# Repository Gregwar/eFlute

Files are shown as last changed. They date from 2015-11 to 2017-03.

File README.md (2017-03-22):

# eFlute

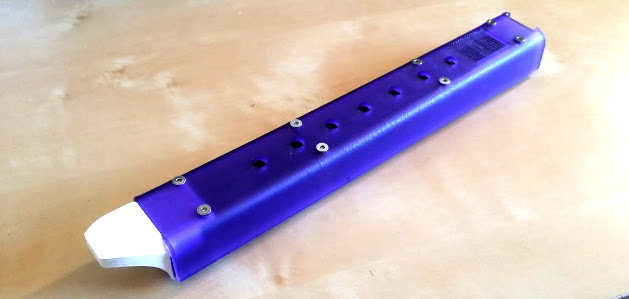
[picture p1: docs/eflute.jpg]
eFlute


**WARNING: This is still a work in progress, which is really poorly documented and with uncertain release date and evolution**

## Video

[Here is a video of an old version of the flute](https://www.youtube.com/watch?v=Vu05FvypGyI)

## License

This project is under CC-BY-NC license. If you're not sure about what you can
do, you should ask the author Grégoire Passault (g.passault@gmail.com).

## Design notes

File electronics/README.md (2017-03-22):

# Electronics

Here are (eagle) files to build the PCB

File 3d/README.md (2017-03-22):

# 3D Design

Here are the 3D files, you'll need Autodesk Inventor to open the ipt/iam
design files

You'll also find STL ready to print for the mouthpiece

Also, there is DXF files to build the acrylic chassis using 3D cutting,
note that you'll also need to bend those pieces.

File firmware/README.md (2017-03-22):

# Firmware

## Bootloader

First, you'll need to flash an USB bootloader on the STM32F103,
you can use either Maple bootloader or ROBOTIS bootloader. This
will be documented later.

## Building and flashing

To build and flash the firmware:

	./prepare.sh
	make
	make install

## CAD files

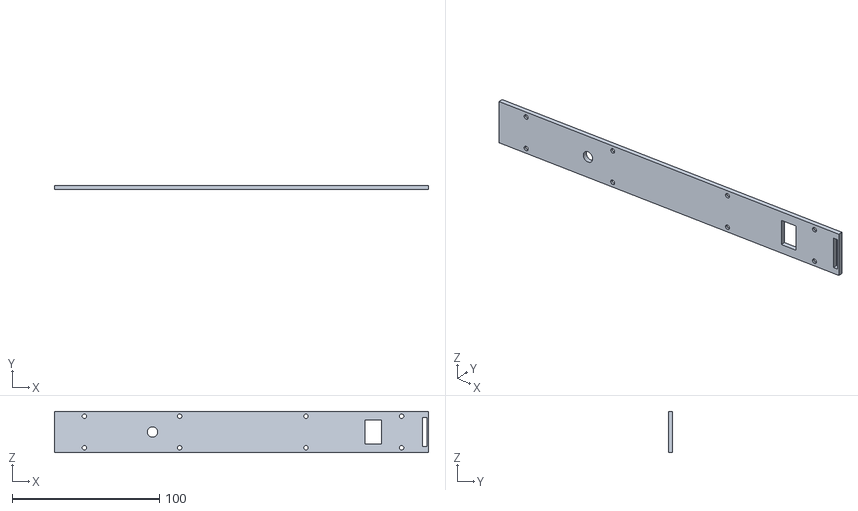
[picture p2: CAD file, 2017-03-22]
3d/bottom.stl
254.0 x 3.00 x 28.0

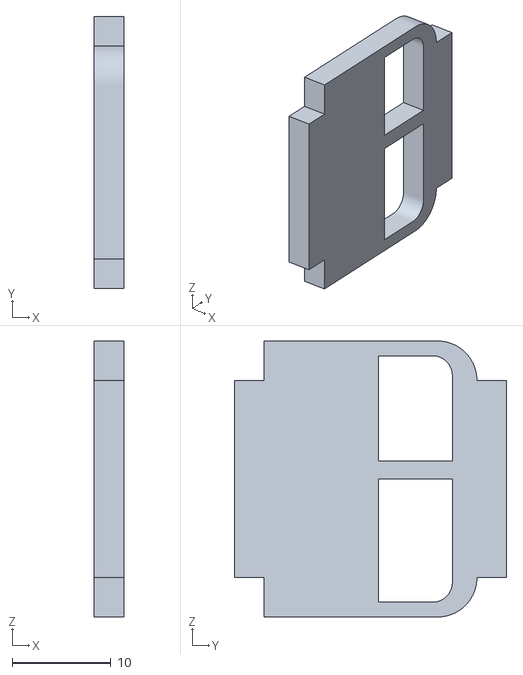
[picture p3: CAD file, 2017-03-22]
3d/connectors.stl
3.00 x 27.6 x 28.0

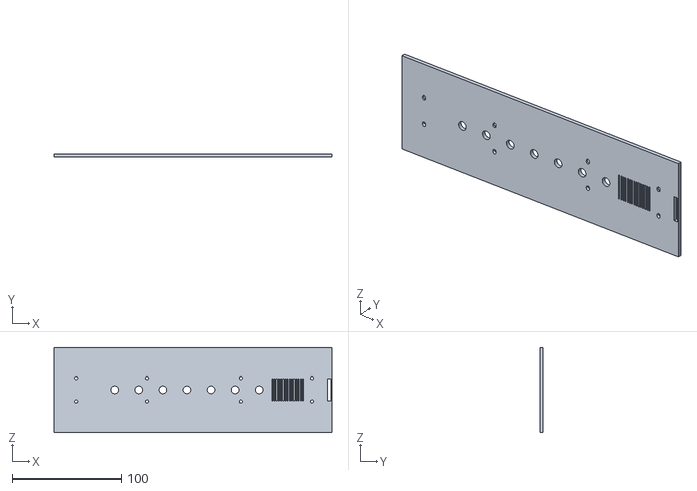
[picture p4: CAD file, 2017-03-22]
3d/top.stl
254.0 x 3.00 x 77.9

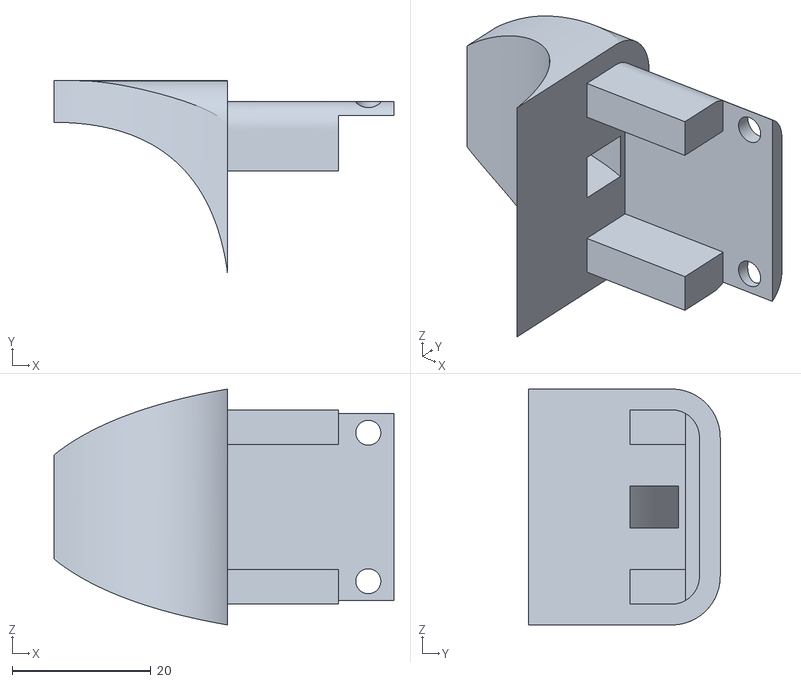
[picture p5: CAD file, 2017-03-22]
3d/mouthpiece.stl
49.0 x 27.6 x 34.0

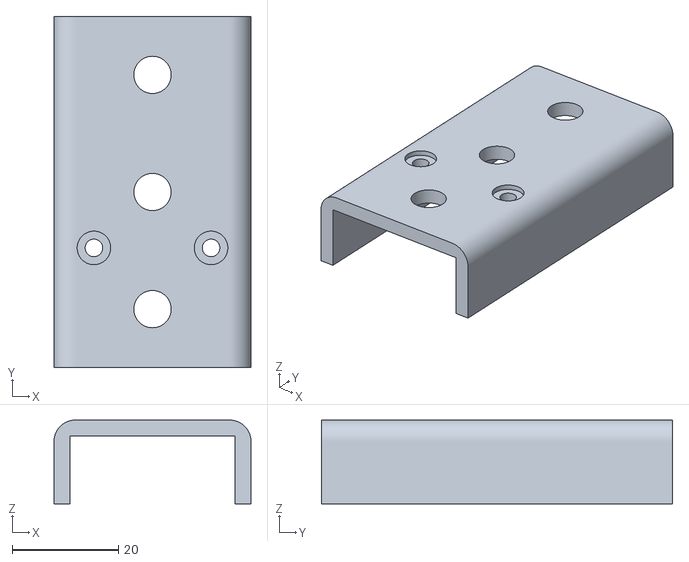
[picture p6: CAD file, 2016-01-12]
3d/part2_top.stl
37.0 x 66.0 x 15.8

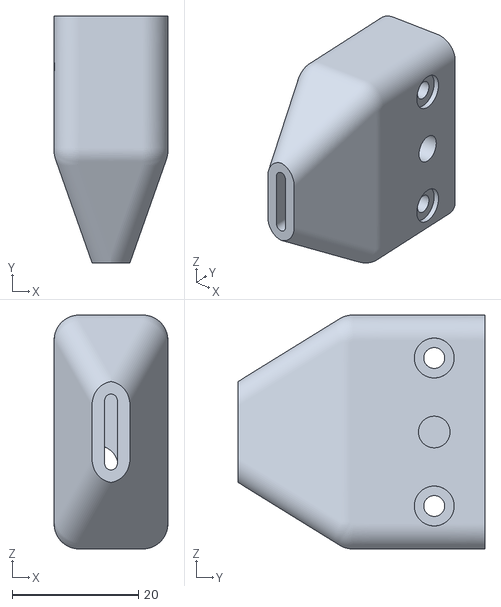
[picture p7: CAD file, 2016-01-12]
3d/mouth.stl
18.0 x 39.0 x 37.0

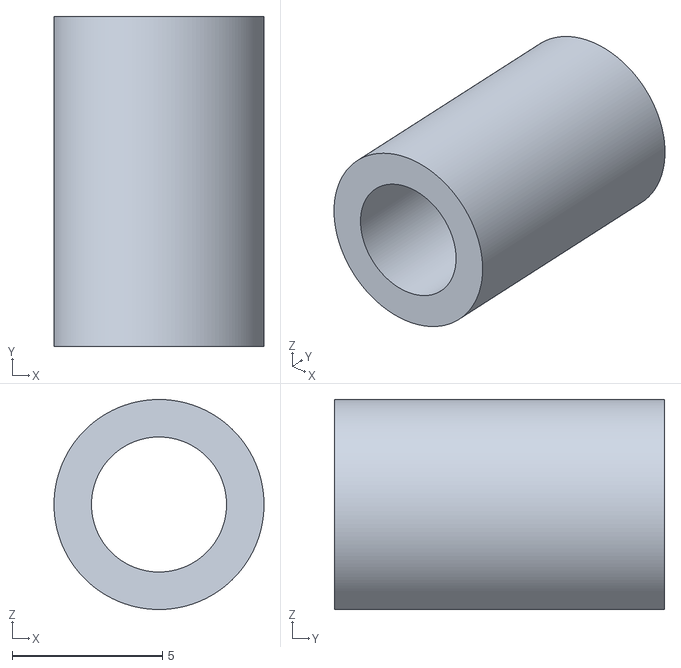
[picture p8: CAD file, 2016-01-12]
3d/entretoise_11.stl
7.00 x 11.0 x 7.00

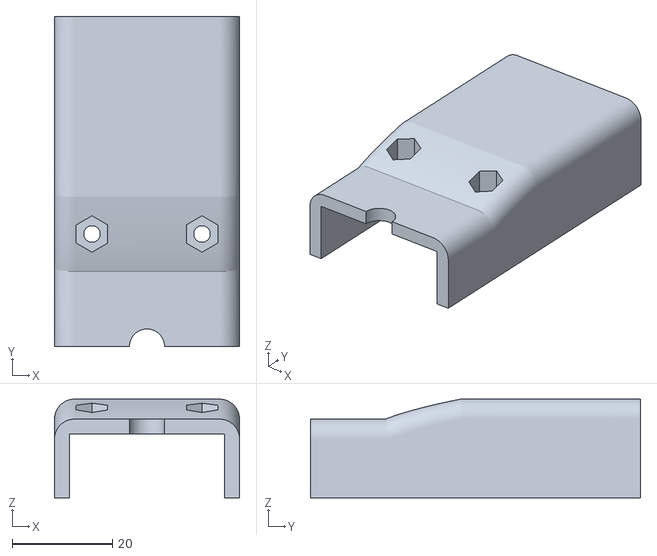
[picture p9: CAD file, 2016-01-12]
3d/part2_bottom.stl
37.0 x 66.0 x 19.8

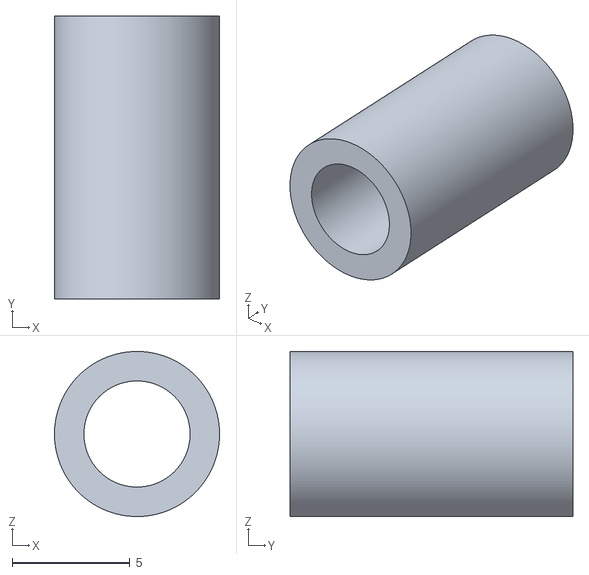
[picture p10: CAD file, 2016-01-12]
3d/entretoise_12.stl
7.00 x 12.0 x 7.00

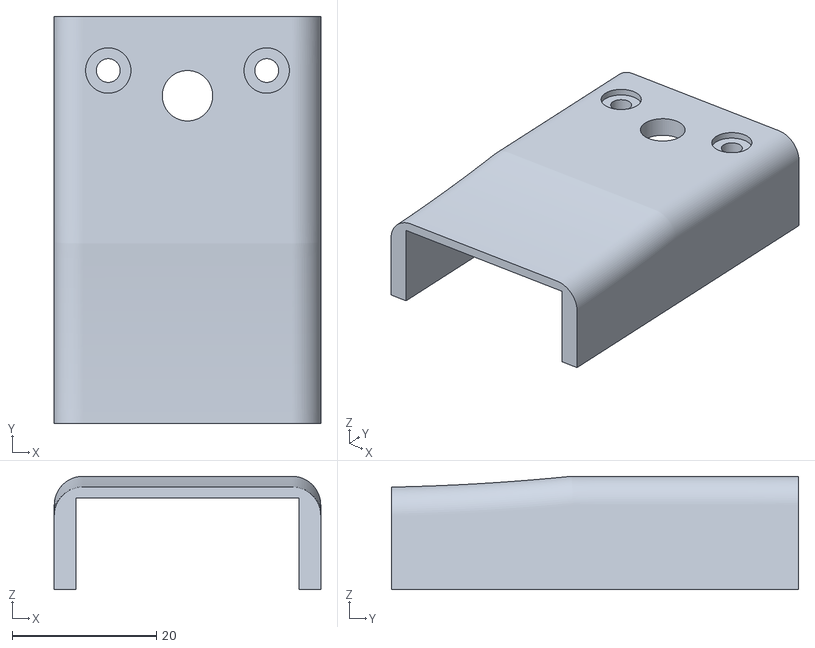
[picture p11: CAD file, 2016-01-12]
3d/part1_top.stl
37.0 x 56.5 x 15.8

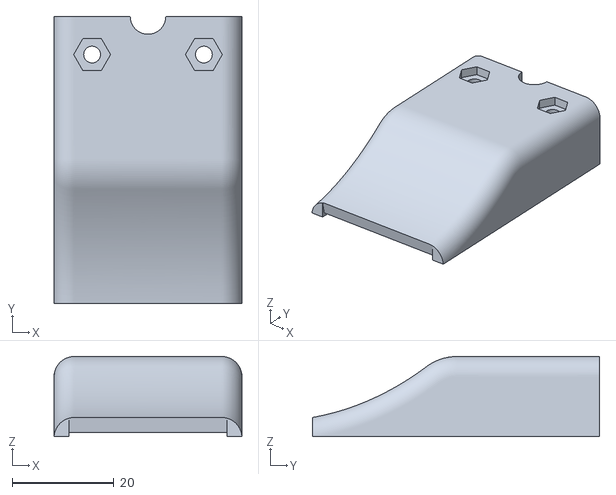
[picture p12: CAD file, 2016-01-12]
3d/part1_bottom.stl
37.0 x 56.5 x 15.8

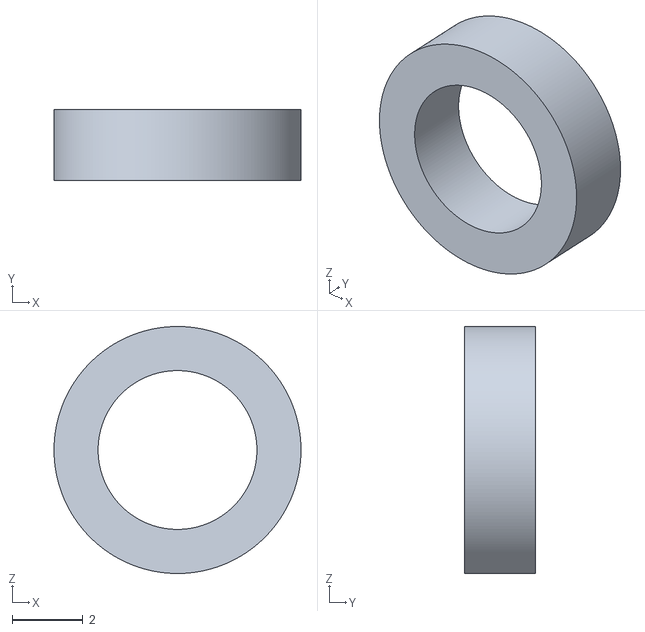
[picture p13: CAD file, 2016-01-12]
3d/entretoise_2.stl
7.00 x 2.00 x 7.00

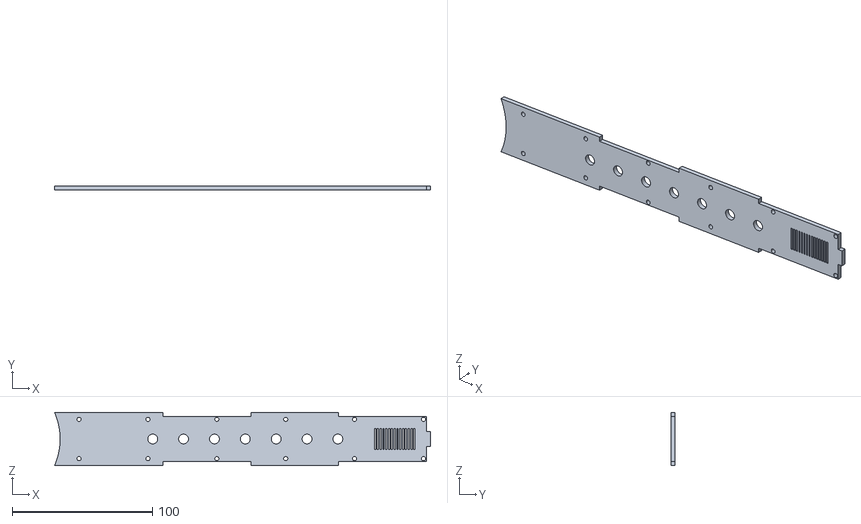
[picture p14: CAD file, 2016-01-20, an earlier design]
3d/v1.1/top.stl
268.0 x 3.00 x 38.0

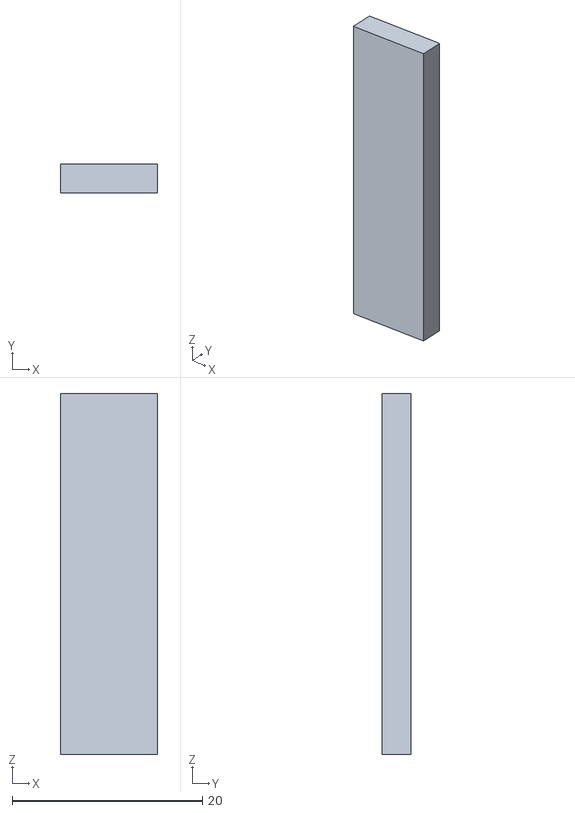
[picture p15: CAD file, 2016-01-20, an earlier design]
3d/v1/renfort.stl
10.2 x 3.00 x 38.0

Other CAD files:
3d/part3_top.stl
3d/v1.1/side.stl
3d/v1/bottom2.stl
3d/v1.1/bottom.stl
3d/bottom.dxf
3d/bottom.ipt
3d/connectors.dxf
3d/connectors.ipt
3d/countersunk.ipt
3d/countersunk_MIR.ipt
3d/electronics.ipt
3d/entretoise_11.ipt
3d/entretoise_12.ipt
3d/entretoise_16.ipt
3d/entretoise_2.ipt
3d/flute.iam
3d/mouth.ipt
3d/mouthpiece.ipt
3d/part1_bottom.ipt
3d/part1_top.ipt
3d/part2_bottom.ipt
3d/part2_top.ipt
3d/part3_top.ipt
3d/spacer_6.ipt
3d/spacer_8.ipt
3d/speaker.ipt
3d/top.dxf
3d/top.ipt
3d/v1.1/bec.ipt
3d/v1.1/bec.stl
3d/v1.1/bottom.ipt
3d/v1.1/bottom2.ipt
3d/v1.1/bottom2.stl
3d/v1.1/bottom_renfort.ipt
3d/v1.1/bottom_renfort.stl
3d/v1.1/button.ipt
3d/v1.1/button.stl
3d/v1.1/cache.ipt
3d/v1.1/coffre.ipt
3d/v1.1/connectors.ipt
3d/v1.1/connectors.stl
3d/v1.1/electronics.ipt
3d/v1.1/flute.iam
3d/v1.1/plate_001.stl
3d/v1.1/renfort.ipt
3d/v1.1/side.ipt
3d/v1.1/side_sym.ipt
3d/v1.1/top.ipt
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

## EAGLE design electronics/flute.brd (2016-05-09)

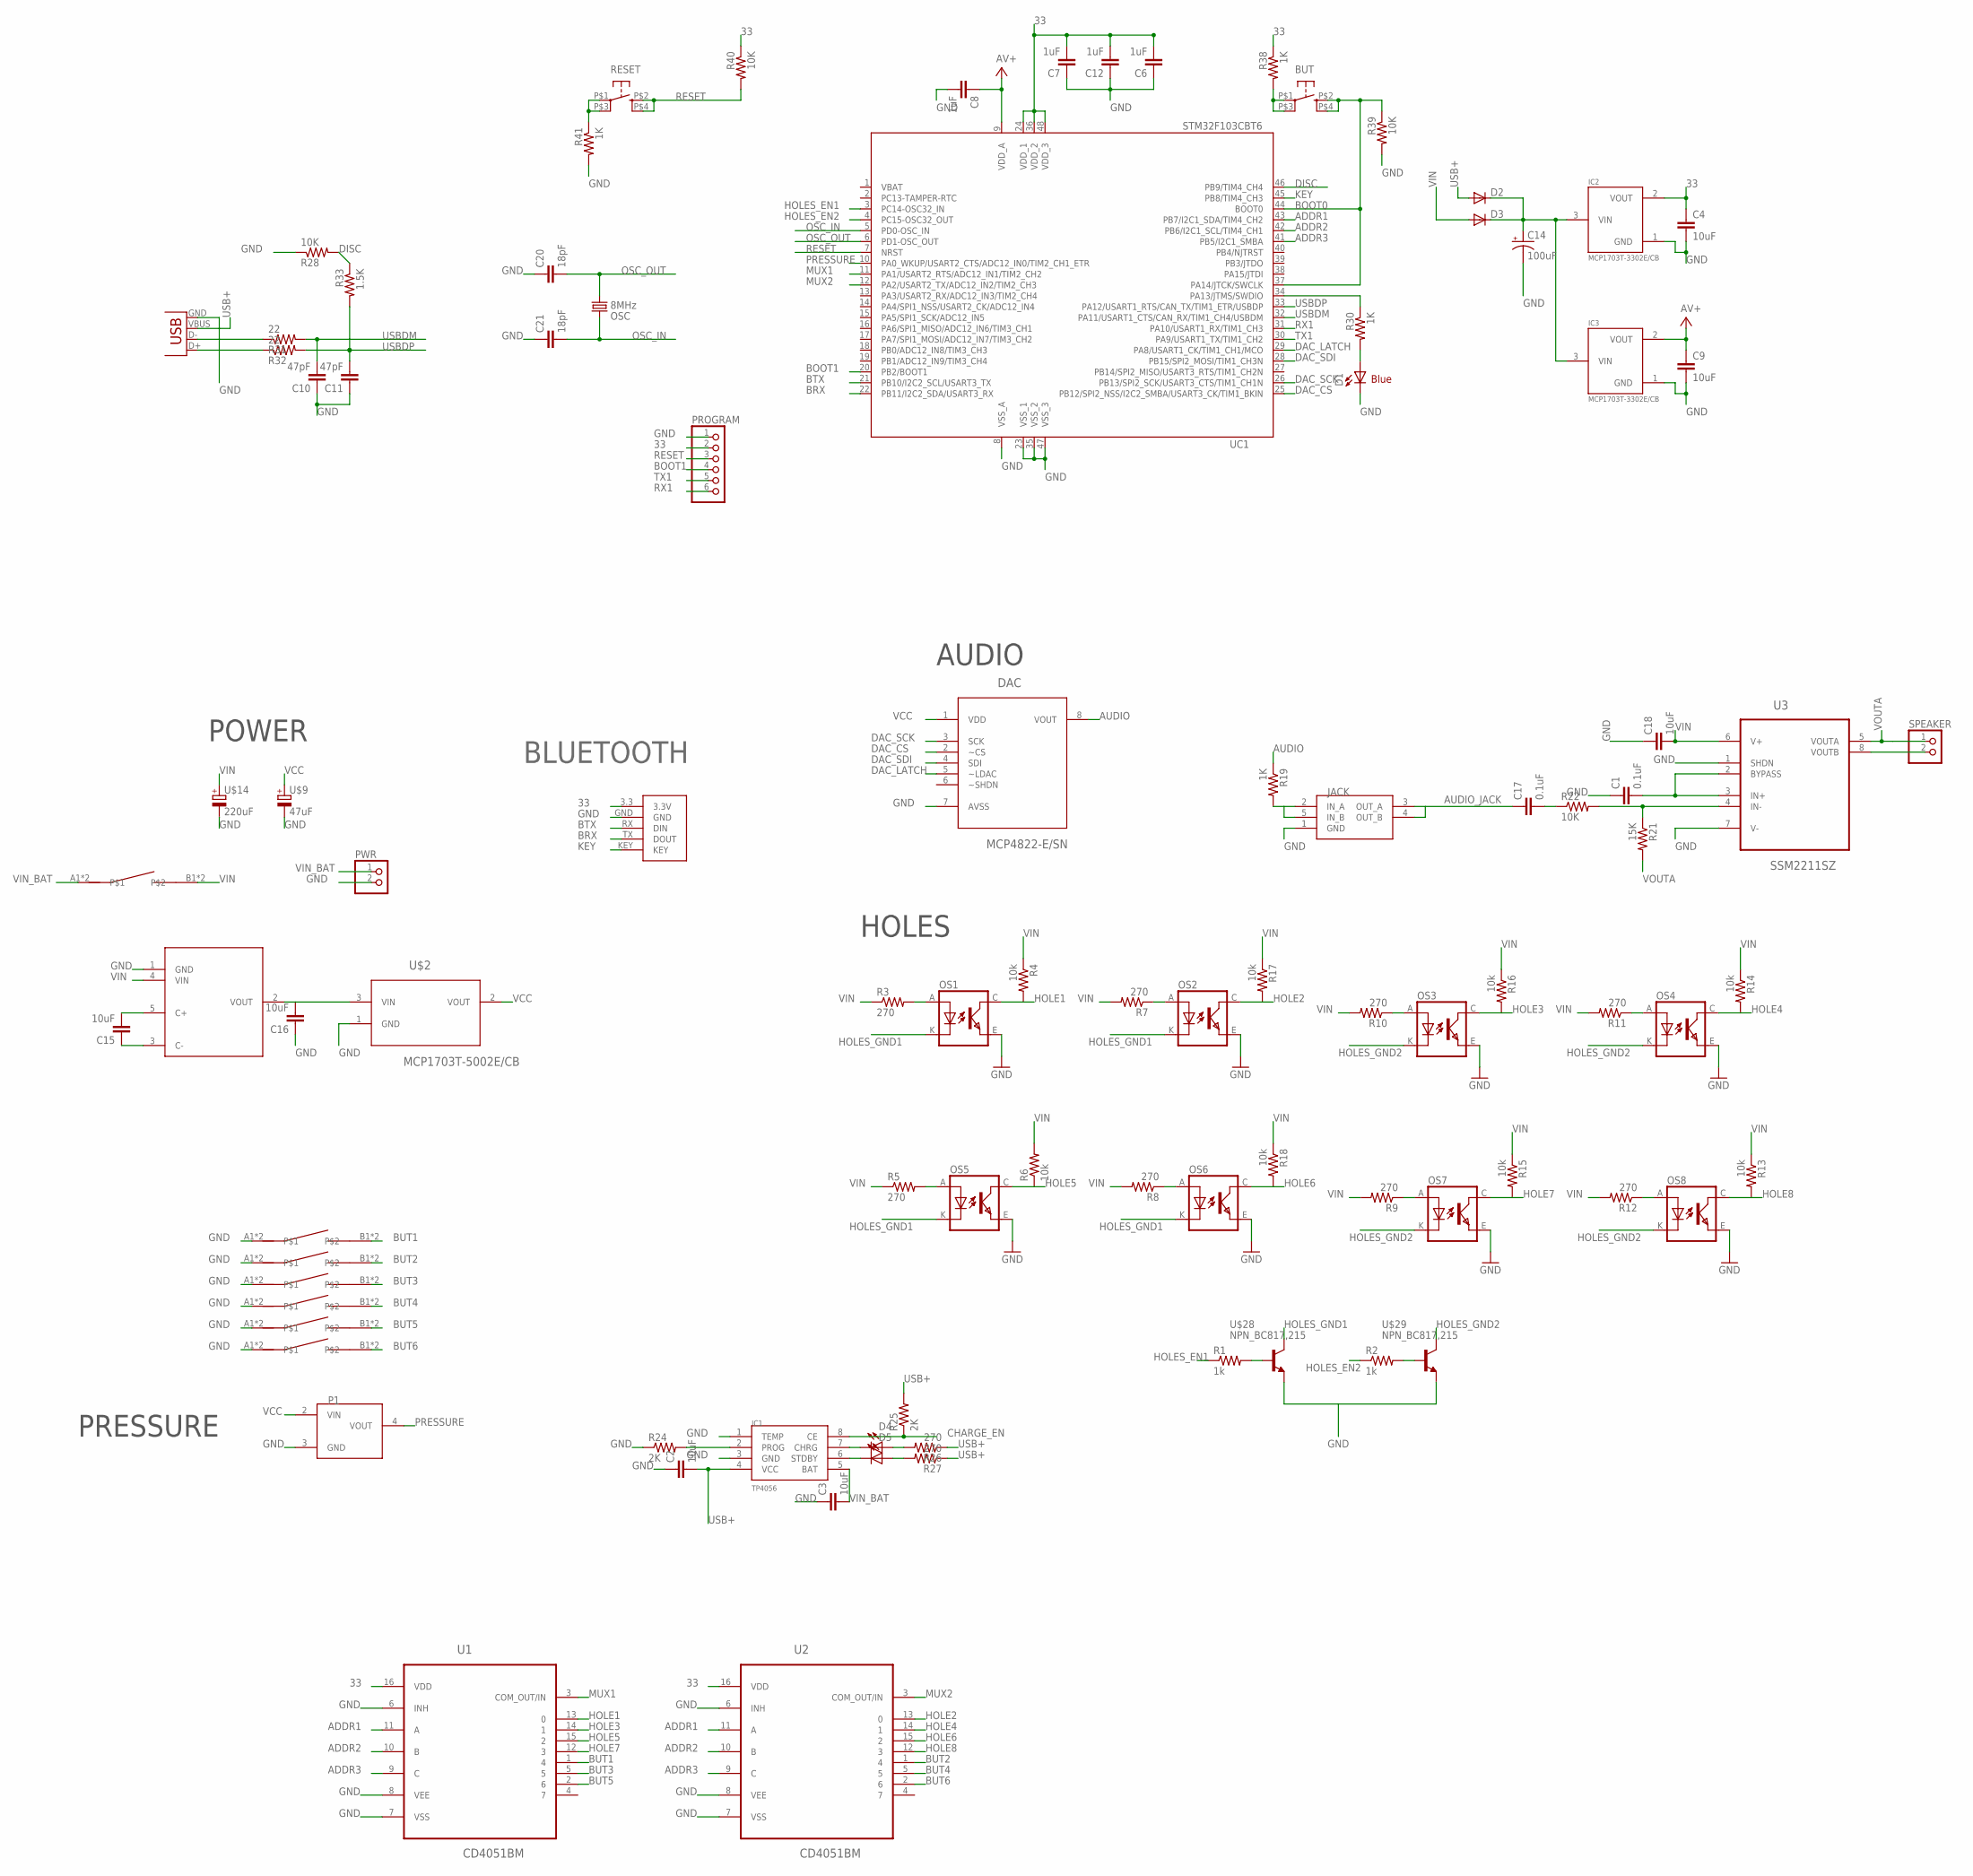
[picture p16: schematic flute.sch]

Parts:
BUT: KMR211GLFS; PUSHBUTTON-KMR241GLFS
C1, C17: 0.1uF; 0805
C2, C3, C4, C9, C15, C16, C18: 10uF; 0805
C6, C7, C8, C12: 1uF; 0805
C10, C11: 47pF; 0805
C14: 100uF; EIA3216
C20, C21: 18pF; 0805
D1: Blue; LED-1206
D2, D3: DIODESOD; SOD-323
D4: Red; LED-1206
D5: Green; LED-1206
DAC: MCP4822-E/SN; SOIC8-N_MC
IC1: TP4056; SOP-8
IC2, IC3: MCP1703T-3302E/CB; SOT23
JACK: JACK; 3F07
OS1, OS2, OS3, OS4, OS5, OS6, OS7, OS8: TCRT5000
OSC: 8MHz; CRYSTAL-SMD-5X3
P1: PRESSURE_SENSOR; MPXV5050GP
PROGRAM: CONNEC_1X066PADS; 6PADS
PWR: CONNEC_1X02BASIC; CONNEC_1X02
R1, R2: 1k; 0805
R3, R5, R7, R8, R9, R10, R11, R12, R26, R27: 270; 0805
R4, R6, R13, R14, R15, R16, R17, R18: 10k; 0805
R19, R30, R38, R41: 1K; 0805
R21: 15K; 0805
R22, R28, R39, R40: 10K; 0805
R24, R25: 2K; 0805
R31, R32: 22; 0805
R33: 1.5K; 0805
RESET: KMR211GLFS; PUSHBUTTON-KMR241GLFS
SPEAKER: CONNEC_1X02BASIC; CONNEC_1X02
U1, U2: CD4051BM; SOIC127P600X175-16N
U3: SSM2211SZ; SOIC127P600X175-8N
U$1: MAX1683; SOT23-5
U$2: MCP1703T-5002E/CB; SOT95P300X145-3N
U$9: 47uF; PANASONIC_D
U$14: 220uF; PANASONIC_D8
U$16: SWITCHKCD11; KCD11
U$18, U$19, U$20, U$21, U$22, U$23: SWITCH6X6X10; SWITCH_6X6X10
U$24: HC05; HC-05
U$28, U$29: NPN_BC817,215; SOT-23
UC1: STM32F103CBT6; LQFP48
X1: USB-MINIB

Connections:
32: BUT.P$2 (2), BUT.P$4 (4), R39.1, UC1.37 (PA14/JTCK/SWCLK), UC1.44 (BOOT0)
33: C4.1, C6.2, C7.2, C12.2, IC2.2 (VOUT), PROGRAM.2, R38.1, R40.1, U1.16 (VDD), U2.16 (VDD), U$24.3.3 (3.3V), UC1.24 (VDD_1), UC1.36 (VDD_2), UC1.48 (VDD_3)
ADDR1: U1.11 (A), U2.11 (A), UC1.43 (PB7/I2C1_SDA/TIM4_CH2)
ADDR2: U1.10 (B), U2.10 (B), UC1.42 (PB6/I2C1_SCL/TIM4_CH1)
ADDR3: U1.9 (C), U2.9 (C), UC1.41 (PB5/I2C1_SMBA)
AUDIO: DAC.8 (VOUT), R19.1
AUDIO_JACK: C17.1, JACK.3 (OUT_A), JACK.4 (OUT_B)
AV+: C8.1, C9.1, IC3.2 (VOUT), UC1.9 (VDD_A)
BOOT1: PROGRAM.4, UC1.20 (PB2/BOOT1)
BRX: U$24.TX (DOUT), UC1.22 (PB11/I2C2_SDA/USART3_RX)
BTX: U$24.RX (DIN), UC1.21 (PB10/I2C2_SCL/USART3_TX)
BUT1: U1.1 (4), U$18.B1, U$18.B2
BUT2: U2.1 (4), U$19.B1, U$19.B2
BUT3: U1.5, U$20.B1, U$20.B2
BUT4: U2.5, U$21.B1, U$21.B2
BUT5: U1.2 (6), U$22.B1, U$22.B2
BUT6: U2.2 (6), U$23.B1, U$23.B2
CHARGE_EN: IC1.8 (CE), R25.1
DAC_CS: DAC.2 (~CS), UC1.25 (PB12/SPI2_NSS/I2C2_SMBA/USART3_CK/TIM1_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)
DAC_LATCH: DAC.5 (~LDAC), UC1.29 (PA8/USART1_CK/TIM1_CH1/MCO)
DAC_SCK: DAC.3 (SCK), UC1.26 (PB13/SPI2_SCK/USART3_CTS/TIM1_CH1N)
DAC_SDI: DAC.4 (SDI), UC1.28 (PB15/SPI2_MOSI/TIM1_CH3N)
DISC: R28.2, R33.1, UC1.46 (PB9/TIM4_CH4)
GND: C1.1, C2.1, C3.1, C4.2, C6.1, C7.1, C8.2, C9.2, C10.1, C11.1, C12.1, C14.C (-), C16.1, C18.1, C20.1, C21.1, D1.C, DAC.7 (AVSS), IC1.1 (TEMP), IC1.3 (GND), IC2.1 (GND), IC3.1 (GND), JACK.1 (GND), OS1.E (EMITTER), OS2.E (EMITTER), OS3.E (EMITTER), OS4.E (EMITTER), OS5.E (EMITTER), OS6.E (EMITTER), OS7.E (EMITTER), OS8.E (EMITTER), P1.3 (GND), PROGRAM.1, PWR.2, R24.1, R28.1, R39.2, R41.2, U1.6 (INH), U1.7 (VSS), U1.8 (VEE), U2.6 (INH), U2.7 (VSS), U2.8 (VEE), U3.1 (SHDN), U3.7 (V-), U$1.1 (GND), U$2.1 (GND), U$9.-, U$14.-, U$18.A1, U$18.A2, U$19.A1, U$19.A2, U$20.A1, U$20.A2, U$21.A1, U$21.A2, U$22.A1, U$22.A2, U$23.A1, U$23.A2, U$24.GND, U$28.2 (E), U$29.2 (E), UC1.8 (VSS_A), UC1.23 (VSS_1), UC1.35 (VSS_2), UC1.47 (VSS_3), X1.GND
HOLE1: OS1.C (COLLECTOR), R4.2, U1.13 (0)
HOLE2: OS2.C (COLLECTOR), R17.2, U2.13 (0)
HOLE3: OS3.C (COLLECTOR), R16.2, U1.14 (1)
HOLE4: OS4.C (COLLECTOR), R14.2, U2.14 (1)
HOLE5: OS5.C (COLLECTOR), R6.1, U1.15 (2)
HOLE6: OS6.C (COLLECTOR), R18.2, U2.15 (2)
HOLE7: OS7.C (COLLECTOR), R15.2, U1.12 (3)
HOLE8: OS8.C (COLLECTOR), R13.2, U2.12 (3)
HOLES_EN1: R1.1, UC1.3 (PC14-OSC32_IN)
HOLES_EN2: R2.1, UC1.4 (PC15-OSC32_OUT)
HOLES_GND1: OS1.K (CATHODE), OS2.K (CATHODE), OS5.K (CATHODE), OS6.K (CATHODE), U$28.3 (C)
HOLES_GND2: OS3.K (CATHODE), OS4.K (CATHODE), OS7.K (CATHODE), OS8.K (CATHODE), U$29.3 (C)
KEY: U$24.KEY, UC1.45 (PB8/TIM4_CH3)
MUX1: U1.3 (COM_OUT/IN), UC1.11 (PA1/USART2_RTS/ADC12_IN1/TIM2_CH2)
MUX2: U2.3 (COM_OUT/IN), UC1.12 (PA2/USART2_TX/ADC12_IN2/TIM2_CH3)
unnamed: C1.2, U3.2 (BYPASS), U3.3 (IN+)
unnamed: R21.1, R22.2, U3.4 (IN-)
unnamed: R1.2, U$28.1 (B)
unnamed: R2.2, U$29.1 (B)
unnamed: OS1.A (ANODE), R3.2
unnamed: D5.A, R27.2
unnamed: OS2.A (ANODE), R7.1
unnamed: JACK.2 (IN_A), JACK.5 (IN_B), R19.2
unnamed: OS3.A (ANODE), R10.1
unnamed: C17.2, R22.1
unnamed: OS4.A (ANODE), R11.1
unnamed: SPEAKER.2, U3.8 (VOUTB)
unnamed: OS5.A (ANODE), R5.2
unnamed: OS6.A (ANODE), R8.1
unnamed: D4.A, R26.2
unnamed: OS7.A (ANODE), R9.1
unnamed: OS8.A (ANODE), R12.1
unnamed: IC1.2 (PROG), R24.2
unnamed: C15.1, U$1.3 (C-)
unnamed: D4.C, IC1.7 (CHRG)
unnamed: D5.C, IC1.6 (STDBY)
unnamed: BUT.P$1 (1), BUT.P$3 (3), R38.2
unnamed: R41.1, RESET.P$1 (1), RESET.P$3 (3)
unnamed: D1.A, R30.2
unnamed: R30.1, UC1.34 (PA13/JTMS/SWDIO)
unnamed: C15.2, U$1.5 (C+)
unnamed: C16.2, U$1.2 (VOUT), U$2.3 (VIN)
unnamed: R31.1, X1.D-
unnamed: R32.1, X1.D+
OSC_IN: C21.2, OSC.3 (2), UC1.5 (PD0-OSC_IN)
OSC_OUT: C20.2, OSC.1, UC1.6 (PD1-OSC_OUT)
PRESSURE: P1.4 (VOUT), UC1.10 (PA0_WKUP/USART2_CTS/ADC12_IN0/TIM2_CH1_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)
RESET: PROGRAM.3, R40.2, RESET.P$2 (2), RESET.P$4 (4), UC1.7 (NRST)
RX1: PROGRAM.6, UC1.31 (PA10/USART1_RX/TIM1_CH3)
TX1: PROGRAM.5, UC1.30 (PA9/USART1_TX/TIM1_CH2)
USB+: C2.2, D2.2 (A), IC1.4 (VCC), R25.2, R26.1, R27.1, X1.VBUS
USBDM: C10.2, R31.2, UC1.32 (PA11/USART1_CTS/CAN_RX/TIM1_CH4/USBDM)
USBDP: C11.2, R32.2, R33.2, UC1.33 (PA12/USART1_RTS/CAN_TX/TIM1_ETR/USBDP)
VBAT: UC1.1 (VBAT)
VCC: DAC.1 (VDD), P1.2 (VIN), U$2.2 (VOUT), U$9.+
VIN: C18.2, D3.2 (A), R3.1, R4.1, R5.1, R6.2, R7.2, R8.2, R9.2, R10.2, R11.2, R12.2, R13.1, R14.1, R15.1, R16.1, R17.1, R18.1, U3.6 (V+), U$1.4 (VIN), U$14.+, U$16.B1, U$16.B2
VIN_BAT: C3.2, IC1.5 (BAT), PWR.1, U$16.A1, U$16.A2
VIN_REGS: C14.A (+), D2.1 (C), D3.1 (C), IC2.3 (VIN), IC3.3 (VIN)
VOUTA: R21.2, SPEAKER.1, U3.5 (VOUTA)

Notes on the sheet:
POWER
PRESSURE
AUDIO
HOLES
BOOT0
Blue
BLUETOOTH

Board: 2 copper layers, 96 parts (9 on the bottom side), 82 nets, no tracks yet.

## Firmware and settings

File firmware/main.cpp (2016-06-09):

#include <stdlib.h>
#include <wirish/wirish.h>
#include <servos.h>
#include <terminal.h>
#include <main.h>
#include <SdFat.h>
#include "holes.h"
#include "blow.h"
#include "samples.h"
#include "bt.h"
#include "dyn.h"
#include "mux.h"

HardwareTimer timer(1);
bool isUSB = false;

TERMINAL_COMMAND(rc, "Go to RC mode")
{
    Serial3.begin(115200);
    terminal_init(&Serial3);
    isUSB = false;
}

TERMINAL_COMMAND(forward,
        "Go to forward mode, the Serial3 will be forwarded to USB and vice-versa. Usage: forward [baudrate]")
{
    int baudrate = 115200;
    char buffer[512];
    unsigned int pos;
    terminal_io()->print("The forward mode will be enabled, ");
    terminal_io()->println("you'll need to reboot the board to return to normal operation");

    if (argc) {
        baudrate = atoi(argv[0]);
    }
    terminal_io()->print("Using baudrate ");
    terminal_io()->println(baudrate);

    Serial3.begin(baudrate);

    while (1) {
        pos = 0;
        while (Serial3.available() && pos < sizeof(buffer)) {
            buffer[pos++] = Serial3.read();
        }

        if (pos > 0) {
            SerialUSB.write(buffer, pos);
        }

        while (SerialUSB.available()) {
            Serial3.write(SerialUSB.read());
        }
    }
}

TERMINAL_PARAMETER_BOOL(bin, "Bin mode", false);
TERMINAL_PARAMETER_INT(binDivider, "Bin divider", 0);

TERMINAL_PARAMETER_FLOAT(volGain, "Vol gain", 20.0);

// #define DEBUG

#define DAC_CS          31
#define DAC_SPI         2
#define DAC_LATCH       27

int buttons[6] = {15, 16, 17, 18, 19, 20};

TERMINAL_COMMAND(but, "Buttons")
{
    for (int k=0; k<6; k++) {
        terminal_io()->print("Button ");
        terminal_io()->print(k);
        terminal_io()->print(": ");
        terminal_io()->println(digitalRead(buttons[k]));
    }
}

HardwareSPI dac_spi(DAC_SPI);
spi_dev *dac_dev;

void dac_init()
{
    dac_spi.begin(SPI_18MHZ, MSBFIRST, 0);

    pinMode(DAC_LATCH, OUTPUT);
    digitalWrite(DAC_LATCH, HIGH);

    pinMode(DAC_CS, OUTPUT);
    digitalWrite(DAC_CS, HIGH);
    dac_dev = dac_spi.c_dev();
}

inline void dac_shut()
{
    int value = 0;
    gpio_write_bit(PIN_MAP[DAC_CS].gpio_device, PIN_MAP[DAC_CS].gpio_bit, LOW);
    char data[2];
    data[0] = (value>>8)&0xff;
    data[1] = (value>>0)&0xff;

    spi_tx_inline(dac_dev, data, 1);
    spi_tx_inline(dac_dev, data+1, 1);
    for (int K=0; K<7; K++) {
        asm volatile("nop");
    }
    gpio_write_bit(PIN_MAP[DAC_CS].gpio_device, PIN_MAP[DAC_CS].gpio_bit, HIGH);
}

inline void dac_set(int value)
{
    value |= (1<<12);
    // value |= (1<<13);
    gpio_write_bit(PIN_MAP[DAC_CS].gpio_device, PIN_MAP[DAC_CS].gpio_bit, LOW);
    // digitalWrite(DAC_CS, LOW);
    char data[2];
    data[0] = (value>>8)&0xff;
    data[1] = (value>>0)&0xff;

    spi_tx_inline(dac_dev, data, 1);
    spi_tx_inline(dac_dev, data+1, 1);
    for (int K=0; K<7; K++) {
        asm volatile("nop");
    }
    gpio_write_bit(PIN_MAP[DAC_CS].gpio_device, PIN_MAP[DAC_CS].gpio_bit, HIGH);
    // digitalWrite(DAC_CS, HIGH);
}

inline void dac_latch()
{
    gpio_write_bit(PIN_MAP[DAC_LATCH].gpio_device, PIN_MAP[DAC_LATCH].gpio_bit, LOW);
    gpio_write_bit(PIN_MAP[DAC_LATCH].gpio_device, PIN_MAP[DAC_LATCH].gpio_bit, HIGH);
}

struct sample *currentSample;
struct sample *currentSamples[DYN_SIZE];
int currentSamplesNb;
TERMINAL_PARAMETER_INT(targetVol, "Target vol", 0);
int vol;
int echoVol, echoPos;
bool compute;
int nextVal;

/*
#define TO_PLAY_SIZE    100
short to_play[TO_PLAY_SIZE];
int to_play_pos;
*/

inline short compute_to_play()
{
    int sumVol = 0, sumVal = 0;
    for (int k=0; k<currentSamplesNb; k++) {
        int dval = currentSamples[k]->values[currentSamples[k]->pos];
        int dvol = currentSamples[k]->vol;
        if (dvol > 0 || currentSamples[k] == currentSample) {
            sumVal += dvol*((dval*vol)/16000);
            sumVol += dvol;

            currentSamples[k]->pos++;
            if (currentSamples[k]->pos >= currentSamples[k]->count) {
                currentSamples[k]->pos = 0;
            }
            if (currentSamples[k] != currentSample) {
                currentSamples[k]->vol -= 1;
            } else {
                if (currentSamples[k]->vol < 1000) {
                    currentSamples[k]->vol += 1;
                }
            }
        }
    }
    int val = 0;
    if (sumVol > 0) {
        val = sumVal/sumVol;
    }
    return 2048+val;
}

TERMINAL_COMMAND(dbg, "dbg")
{
    terminal_io()->print("There is ");
    terminal_io()->println(currentSamplesNb);
    for (int k=0; k<currentSamplesNb; k++) {
        terminal_io()->print("Sample #");
        terminal_io()->print(k);
        terminal_io()->print(": ");
        terminal_io()->print(currentSamples[k]->vol);
        terminal_io()->println();
    }
}

void setSample(struct sample *sample)
{
    if (sample != currentSample) {
        currentSample = sample;
        // Checking if the sample is already present in the list
        for (int k=0; k<currentSamplesNb; k++) {
            if (currentSamples[k] == sample) {
                return;
            }
        }
        // Adding it
        currentSamples[currentSamplesNb++] = sample;
    }
}

TERMINAL_COMMAND(dac, "Dac debug")
{
    dac_set(atoi(argv[0]));
    dac_latch();
}

void interrupt()
{
    if (bin) {
        binDivider++;
        return;
    } else {
        static int k = 0;

        if (currentSample != NULL && vol > 0) {
            dac_latch();
            int val = compute_to_play();

#ifdef DEBUG
            terminal_io()->println(val);
#else
            dac_set(val);
#endif
        }

        k++;
        if (k > 2) {
            k = 0;
            if (vol < targetVol) vol++;
            if (vol > targetVol) vol--;
        }
    }
}

TERMINAL_COMMAND(vol, "See the vol")
{
    terminal_io()->println(vol);
}

/**
 * Setup function
 */
void setup()
{
    for (int k=0; k<6; k++) {
        pinMode(buttons[k], INPUT_PULLUP);
    }

    // Bluetooth setup
    bt_init();

    // Terminal
    terminal_init(&Serial3);

    // DAC
    dac_init();


#ifdef DYN
    dyn_init();
#endif
    
    // Mux
    mux_init();

    // Initializing blow
    blow_init();

    // Holes
    holes_init();

    // Remapping SPI1 for sd card
    //    afio_remap(AFIO_REMAP_SPI1);

    // Ticking @32000
#ifndef DEBUG
    timer.pause();
    timer.setPrescaleFactor(1);
    timer.setOverflow(1632);
    timer.setCompare(TIMER_CH1, 1);
    timer.attachCompare1Interrupt(interrupt);
    timer.refresh();
    timer.resume();
#endif
    currentSample = NULL;
    currentSamplesNb = 0;

    for (int k=0; k<DYN_SIZE; k++) {
        dyn[k].pos = 0;
        dyn[k].vol = 0;
    }
}

void inhale()
{
    int note = -1;
    for (int k=0; k<DYN_SIZE; k++) {
        if (currentSample == &dyn[k]) note = k;
    }
    /*
       terminal_io()->print("Inhale: ");
       terminal_io()->println(note);
       */

    if (note == 0) {
        set_freq(523.25);
    }
    if (note == 1) {
        set_freq(698.46);
    }
    if (note == 2) {
        set_freq(783.99);
    }

    dyn_gen();
}

int holes_st = 0;
int blows_st = 0;

/**
 * Loop function
 */
void loop()
{
    if (SerialUSB.available() && !isUSB) {
        isUSB = true;
        terminal_init(&SerialUSB);
    }  
    static int k = 0;

#ifdef DEBUG
    interrupt();
#endif

    // Terminal
    terminal_tick();

    if (k++ > 10) {
        k = 0;
        // Ticking holes
        if (holes_tick()) {
            holes_st++;
            char holes = holes_value();
            switch (holes) {
#ifdef DYN
                case 0b11111111:
                    setSample(&dyn[0]);
                    break;
                case 0b10111111:
                    setSample(&dyn[1]);
                    break;
                case 0b10011111:
                    setSample(&dyn[2]);
                    break;
                case 0b10001111:
                    setSample(&dyn[3]);
                    break;
                case 0b10000111:
                    setSample(&dyn[4]);
                    break;
                case 0b10000011:
                    setSample(&dyn[5]);
                    break;
                case 0b10000001:
                    setSample(&dyn[6]);
                    break;
                case 0b01111111:
                    setSample(&dyn[7]);
                    break;
                case 0b00111111:
                    setSample(&dyn[8]);
                    break;
                case 0b00011111:
                    setSample(&dyn[9]);
                    break;
                case 0b00001111:
                    setSample(&dyn[10]);
                    break;
                case 0b00000111:
                    setSample(&dyn[11]);
                    break;
                case 0b00000011:
                    setSample(&dyn[12]);
                    break;
                case 0b00000001:
                    setSample(&dyn[13]);
                    break;
#else
                case 0b11111111:
                    currentSample = &sample_c;
                    break;
                case 0b10111111:
                    currentSample = &sample_d;
                    break;
                case 0b10011111:
                    currentSample = &sample_e;
                    break;
                case 0b10001111:
                    currentSample = &sample_f;
                    break;
                case 0b10000111:
                    currentSample = &sample_g;
                    break;
                case 0b10000011:
                    currentSample = &sample_a;
                    break;
                case 0b10000001:
                    currentSample = &sample_b;
                    break;
                case 0b10000010:
                    currentSample = &sample_c2;
                    break;
#endif
            }
        }
    }

    // Adjusting volume
    if (blow_tick()) {
        blows_st++;
        static bool inhaling = false;
        int tmp = (blow_value()/100)-30;

        if (inhaling) {
            if (tmp > -40) inhaling = false;
        } else {
            if (tmp < -300) {
                inhaling = true;
                inhale();
            }
        }
        tmp *= volGain;
        if (tmp < 0) tmp = 0;
        if (tmp > 2000) tmp = 2000;
        targetVol = tmp;
    }

    // Checking if samples can be removed from the list
    for (int k=0; k<currentSamplesNb; k++) {
        if (currentSamples[k]->vol <= 0 && currentSamples[k] != currentSample) {
            currentSamples[k] = currentSamples[currentSamplesNb-1];
            currentSamplesNb--;
        }
    }

    if (binDivider > 100) {
        char packet[6];
        binDivider -= 44;
        packet[0] = 0xaa;
        packet[1] = 0xaa;
        packet[2] = holes_value();
        int b = blow_value();
        if (b < 0) b = 0;
        b /= 30;
        packet[3] = (b>>8)&0xff;
        packet[4] = (b>>0)&0xff;
        packet[5] = 0x00;
        terminal_io()->write(packet, 6);
    }
}

TERMINAL_COMMAND(test, "Test")
{
    dyn_gen();
    if (argc == 0) {
        targetVol = 400;
    } else {
        targetVol = atoi(argv[0]);
    }
    for (int k=0; k<DYN_SIZE; k++) {
        setSample(&dyn[k]);
        delay(100);
    }
    targetVol = 0;
}

TERMINAL_COMMAND(st, "Stats")
{
    int elapsed = millis();
    float b = blows_st*1000.0/elapsed;
    float h = holes_st*1000.0/elapsed;

    terminal_io()->print("Blows: ");
    terminal_io()->println(b);
    terminal_io()->print("Holes: ");
    terminal_io()->println(h);
}

TERMINAL_COMMAND(benchmark, "Benchmark holes")
{
    int start, len;

    targetVol = 100;
    HardwareTimer timer(1);
    timer.pause();
    setSample(&dyn[0]);

    terminal_io()->println("Doing 1000 holes cycles");
    start = micros();
    for (int k=0; k<1000; k++) {
        holes_cycle();
    }
    len = micros()-start;
    terminal_io()->print("µs: ");
    terminal_io()->println(len);

    terminal_io()->println("Calling interrupt 44100 times");
    start = micros();
    for (int k=0; k<44100; k++) {
        interrupt();
    }
    len = micros()-start;
    terminal_io()->println(len);

    terminal_io()->println("Reading 160 holes");
    len = 0;
    for (int k=0; k<160; k++) {
        start = micros();
        if (blow_tick()) {
            len += micros()-start;
        } else {
            k--;
        }
    }
    terminal_io()->println(len);

    terminal_io()->println("Latching the DAC 44100 times");
    start = micros();
    for (int k=0; k<44100; k++) {
        dac_latch();
    }
    len = micros()-start;
    terminal_io()->println(len);

    timer.resume();
}

TERMINAL_COMMAND(ss, "Small sinus")
{
    targetVol = atoi(argv[0]);
    setSample(&dyn[0]);
    delay(1000);
}

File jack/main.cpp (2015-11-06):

#include <signal.h>
#include <iostream>
#include <unistd.h>
#include "Midi.h"
#include "Flute.h"
    
bool terminate = false;

void signal_handler(int sig)
{
    terminate = true;
}

int main()
{
    signal(SIGTERM, signal_handler);
    signal(SIGINT, signal_handler);

    Midi midi;
    Flute flute("/dev/ttyACM0");
    int k = 0;

    while (!terminate) {
        auto sample = flute.readSample();

        if (k++ > 50) {
            k = 0;
            system("clear");
            sample.print();
            midi.setInstrument(74);
        }

        int note = 0;
        switch (sample.holes) {
                case 0b11111111:
                    note = 60;
                    break;
                case 0b10111111:
                    note = 62;
                    break;
                case 0b10011111:
                    note = 64;
                    break;
                case 0b10001111:
                    note = 65;
                    break;
                case 0b10000111:
                    note = 67;
                    break;
                case 0b10000011:
                    note = 69;
                    break;
                case 0b10000001:
                    note = 71;
                    break;
                case 0b10000010:
                    note = 72;
                    break;
                case 0b00000010:
                    note = 74;
                    break;
                case 0b00011111:
                    note = 76;
                    break;
        }

        if (note != 0) {
            note += 12;
            if (sample.blow > 10) {
                midi.startNote(note, 127);
            } else {
                midi.stopNote(note, 127);
            }
        }
    }
}

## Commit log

2015-08-10 Electronics model
    [electronics.ipt]
2015-08-21 Filtering blow
2015-08-24 static sized dyn samples
2015-11-03 Starting V1
    [flute.brd, flute.sch]
2015-11-04 Routed V1 (to be checked)
    [flute.brd, flute.sch]
2015-12-28 v1 (wip)
    [bec.ipt, bec.stl, bottom.ipt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]
2015-12-28 v1 mecha (wip)
    [bec.ipt, bottom.ipt, bottom2.ipt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]
2016-01-12 Bottom plat
    [bottom.ipt, bottom2.ipt, side.ipt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]
2016-01-12 coffrage piles
    [bec.ipt, coffre.ipt, electronics.ipt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]
2016-01-20 Holes M3, better footprint for buttons
    [flute.brd, flute.sch]
2016-01-21 elec v1.1 (wip)
    [flute.brd, flute.sch]
2016-04-14 AMP SSM2211
    [flute.brd, flute.sch]
2016-04-15 Version simplified
    [flute.brd, flute.sch]
2016-05-09 Fixing resistor place
    [flute.brd, flute.sch]
2016-06-08 BT & fixes for v1.2
    [bt.cpp, holes.cpp, main.cpp]
2016-07-22 Reducing optical leds power consumption
2017-03-20 electronics & readme
    [flute.brd, flute.sch]
2017-03-20 3d tweaking folder
    [bec.ipt, bec.stl, bottom.ipt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]
2017-03-22 3d update
    [bec.ipt, bec.stl, bottom.dxf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]
2017-03-22 Renaming to en mouthpiece
    [flute.iam, mouthpiece.ipt, mouthpiece.stl]
2017-03-22 Updating names
    [bottom.ipt, bottom.stl, connectors.stl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]

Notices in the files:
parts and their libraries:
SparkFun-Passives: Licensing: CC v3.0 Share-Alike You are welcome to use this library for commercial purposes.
